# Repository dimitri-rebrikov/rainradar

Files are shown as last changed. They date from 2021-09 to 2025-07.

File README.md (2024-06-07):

# rainradar

Rain Radar (German: Regenradar)  displays the rain forecast on a 32x8 led matrix.
It shows the intensity of the rain for the next 2 hours with 5 minutes resolution 
and the intensity of the rain for the 6 hours (following the 2 hours) with 1 hour resolution.

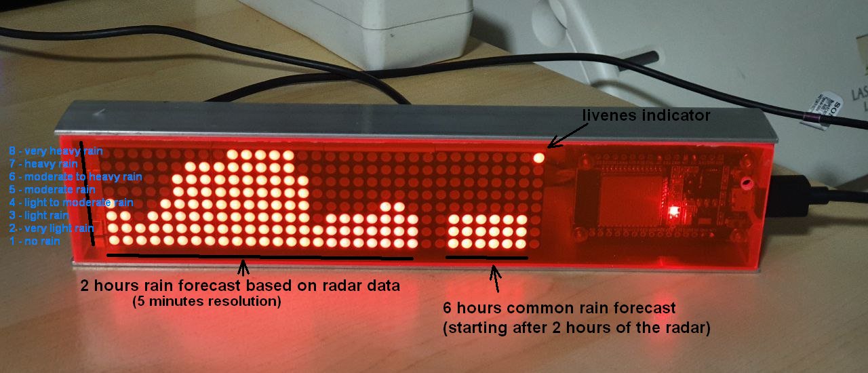
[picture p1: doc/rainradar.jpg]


# common
The Rain Radar consist of:

Frontend Device:
- an ESP32 micro controller
- a chain of four MAX7219 8x8 LED matrices
- source code implemented in MycroPython accessing to the backend and visualising the rain forecast data on the matrix

Backend/Online Services:
- AWS Lambda collecting rain radar data (Radolan RV) from the DWD (German Federal Weather Service) for all Gemran postal indexes (PLZ's)
- AWA Lambda collecting rain forecast data (Mosmix) from the DWD for all German postal indexes
- AWD Lambda providing rain radar and rain forecast data on a HTTP GET request with a German postal index as query parameter

The project is inspired by the project from the German Make Magazine https://github.com/MakeMagazinDE/LED-Laufschrift

# user manual for the device

See [User Manual](doc/manual/MANUAL.md)

# assembly of the device

See [Assembly](doc/assembly/ASSEMBLY.md)
# setup of the device

- install Silicon Labs CP210x VCP driver from silabs.com so your PC can communicate with the ESP32 
- install Python 3.x as the software used below depends on it
- flash the MicroPython image on the ESP32 as described in https://docs.micropython.org/en/latest/esp32/tutorial/intro.html
  - `pip3 install esptool`
  - `esptool.py erase_flash`
  - `esptool.py  write_flash -z 0x1000  ~/Downloads/esp32/micropython/esp32-20210902-v1.17.bin` (assuming you downloaded the image into %HOMEPATH%/Downloads/esp32/micropython)
- install the tool to copy the files to ESP32
  - `pip3 install adafruit-ampy`
  - `ampy --port COM4 ls` (Change COM4 to the port number valid on your PC. Look into the device manager for this. If ampy hangs try to add the delay paramter to the command, i.e. `ampy --port COM4 -d 1 ls`)
- download the `max7219.py` module from  https://github.com/mcauser/micropython-max7219
- upload the max7219 module to the ESP32
  - `ampy --port COM4 mkdir lib`
  - `ampy --port COM4 put ~/Downloads/esp32/micropython/max7219.py lib/max7219.py` (assuming you downloaded the module into %HOMEPATH%/Downloads/esp32/micropython)
  - `ampy --port COM4 ls lib`
- download this project (i.e. https://github.com/dimitri-rebrikov/rainradar)
- upload the rainradar code (i.e. the python modules *.py) to the ESP32
  - `ampy --port COM4 put ~/Downloads/esp32/rainradar/rainradar/ .` (assuming you downloaded the project into %HOMEPATH%/Downloads/esp32/rainradar)
  - `ampy --port COM4 ls`
- restart ESP32 by disconnecting/connecting the power supply (i.e. USB)

# backend

See [Backend](aws-backend/BACKEND.md)

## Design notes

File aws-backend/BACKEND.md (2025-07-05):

# setup
Theoretically you don't need your own backend as the frontend device will use my instance of the backend by default.

But for the case you want to have and use your own instance, here is the short description:
(to do this you need to have basic knowledge about Amazon Web Services)

- create 3 AWS Lambdas using the zipped content of the rainradar_* directories. For the rainradar_rv_update lambda you will also need to create a python layer, see the chapter below.
- configure the S3 bucket with the name "rainradar" and configure the read/write access to it for all 3 lambdas
- test all 3 lambdas
- create Event Bridge with 1 hour rate for the rainradar_mosmix_update lambda
- create Event Bridge with 2-5 min rate for the rainradar_rv_update lambda
- create API Gateway for the rainradar_get lambda. For the API Gateway you may also want to create throttling to prevent unexpected costs if someone runs a request attack to your endpoint
- the current frontend source code contains the hardcoded URL of my API Gateway so you need to adjust it to use you own

## rainradaf_rv_update python layer
The rainradar_rv_update lambda uses functions depending on the h5py python library. 
This library not only not included into the standard python distribution available on the AWS but also has hardware dependent part. So you need to create a layer for this

Commands to create the layer zip on your local machine:
- install the same python version you will use for the lambdas in AWS
- `mkdir python`
- `pip install h5py --platform manylinux2014_x86_64 --only-binary=:all: -t python`
- `zip -r layer.zip python/` (if you don't have zip command, just use the zipper of your choice, but pay attention that the 'python' directory is preserved inside of the the zip)

Then you just need to create a new layer in your AWS environment and upload the 'layer.zip' as its content.

Later during the creation of the rainradar_rv_update lambda you shall configure it to use this layer.

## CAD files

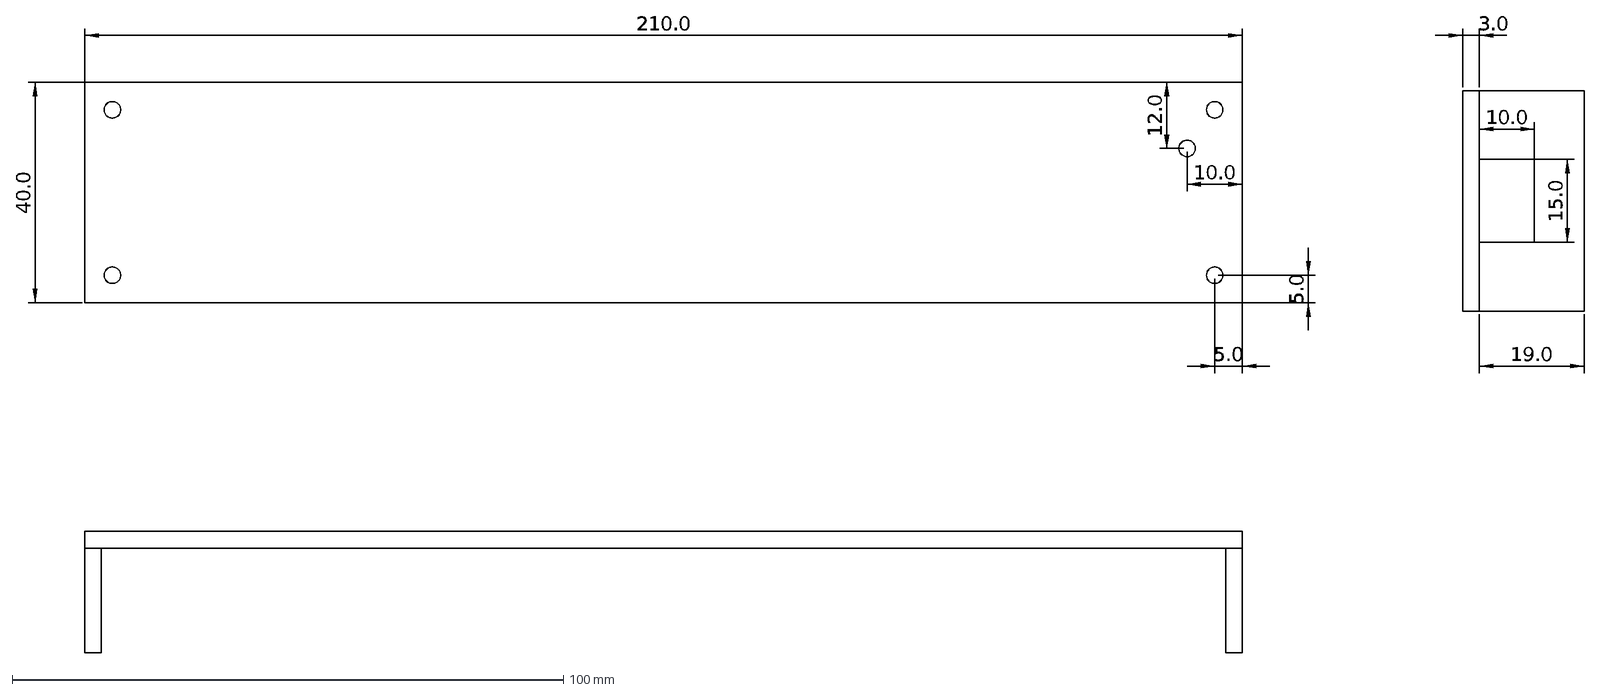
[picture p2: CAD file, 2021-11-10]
doc/assembly/lid.dxf
5.0
40.0
210.0
12.0
10.0
3.0
15.0
19.0

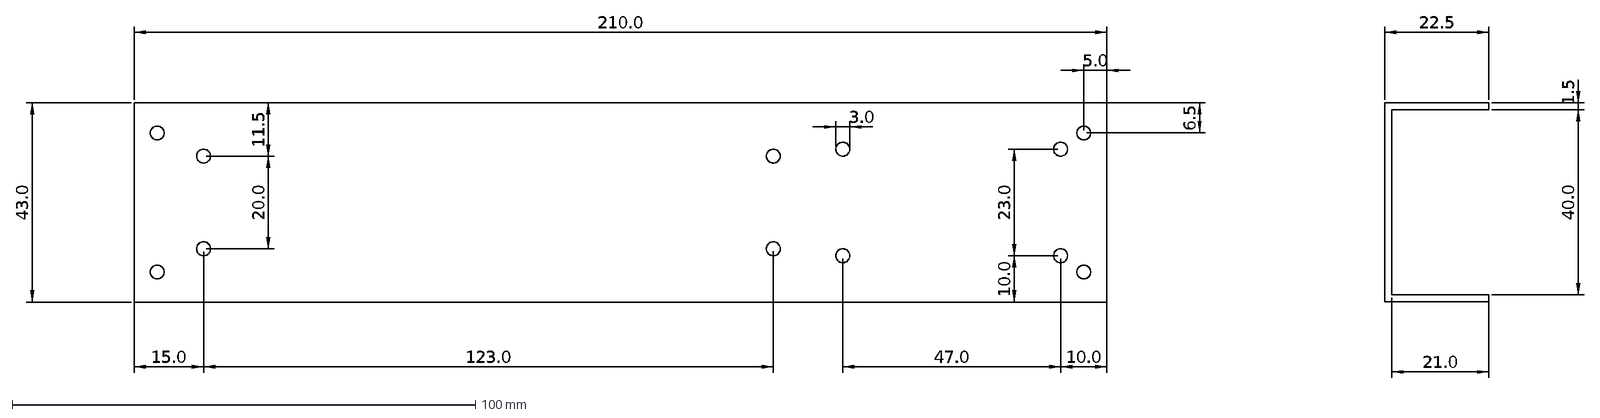
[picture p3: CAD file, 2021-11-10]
doc/assembly/casing.dxf
210.0
22.5
40.0
1.5
21.0
3.0
47.0
123.0
10.0
5.0
6.5
15.0
43.0
23.0
20.0
11.5

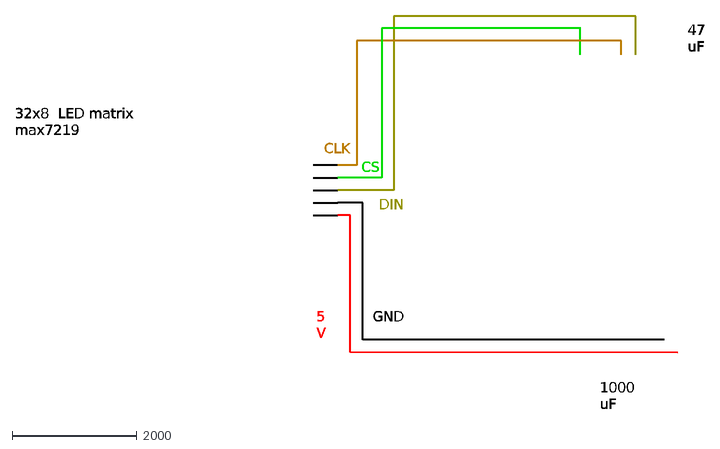
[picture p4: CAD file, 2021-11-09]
doc/assembly/schematic.dxf
32x8 LED matrix max7219
47 uF
1000 uF
GND
5 V
CLK
CS
DIN

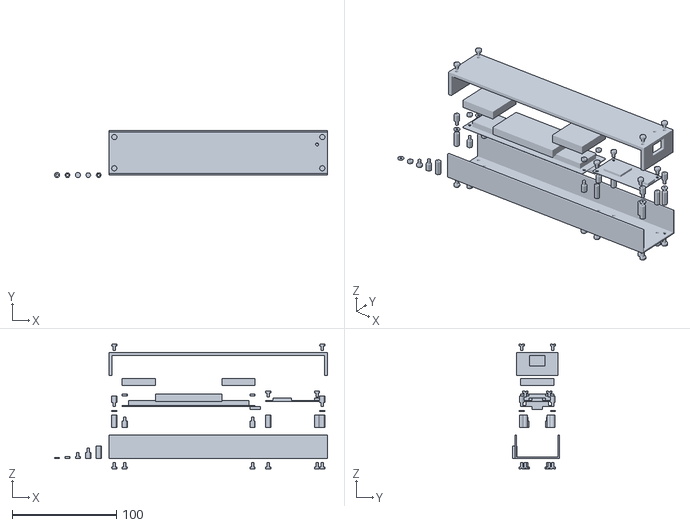
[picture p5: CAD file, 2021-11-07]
doc/assembly/exploded_view.stl
262.5 x 45.5 x 120.0

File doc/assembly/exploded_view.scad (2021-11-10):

$fn=20;

/*
positions of the drilling holes
*/
dhLid1=[5,6.5,0];
dhLid2=[5,36.5,0];
dhLid3=[205,6.5,0];
dhLid4=[205,36.5,0];
dhLed1=[15,11.5,0];
dhLed2=[15,31.5,0];
dhLed3=[138,11.5,0];
dhLed4=[138,31.5,0];
dhEsp1=[153,10,0];
dhEsp2=[153,33,0];
dhEsp3=[200,10,0];
dhEsp4=[200,33,0];

module parts() {
    // just to show all parts necessary
    translate([-10,0,0]) standoff12FF();
    translate([-20,0,0]) standoff06MF();
    translate([-30,0,0]) screw();
    translate([-40,0,0]) screwNut();
    translate([-50,0,0]) washer();
}

module explode_view() {
    // explode view of elements
    casingWithHoles();
    translate([0,0,-10]) bottomScrews();
    translate([0,0,30]) {
        ledStandoffs();
        espStandoffs();
        lidStandoffs1();
    }
    translate([0,0,45]) lidWashers();
    translate([0,0,60]) lidStandoffs2();
    translate([0,0,50]) ledBase();
    translate([0,0,55]) esp();
    translate([0,0,65]) espScrews();
    translate([0,0,60]) ledScrewNuts();
    translate([0,0,70]) ledUnmounted();
    translate([0,0,80]) lid();
    translate([0,0,110]) lidScrews();
}

parts();
explode_view();
// or
// projection for creating a dxf file for casing drillings
//projection(cut=true) translate([0,0, -1])
//    casingWithHoles();
// or
// projection for creating a dxf file for casing side view
//projection(cut=true) translate([0,0, 1]) rotate([0,90,0])
//    casingWithHoles();
// or
// projection for creating a dxf file for lid
//projection(cut=true) translate([0,0, -20])
//    lid();
// or
// projection for creating a dxf file for lid USB side
//projection(cut=true) translate([0,0, 209]) rotate([0,90,0])
//    lid();
// or
// projection for creating a dxf file for lid cross section
//projection(cut=true) translate([0,0,2]) rotate([-90,0,0])
//    lid();


module standoff12FF() {
    /*
    standoff m2.5 x 12 mm
    */
    difference(){
        cylinder(d=5,h=12,$fn=6);
        cylinder(d=2.5,h=12,$fn=50);
    }
}

module standoff06MF() {
    /*
    standoff m2.5 x 6 mm + 4 mm
    */
    difference(){
        cylinder(d=5,h=6,$fn=6);
        cylinder(d=2.5,h=5,$fn=50);
    }
    translate([0,0,4]) cylinder(d=2.5,h=6,$fn=50);
}

module screw() {
    /*
    screw m2.5
    */
    difference() {
        cylinder(d=5,h=2,$fn=50);
        translate([-2.5,-0.5,0]) cube([5, 1, 1]);
    }
    translate([0,0,2]) cylinder(d=2.5,h=4,$fn=50);
}

module screwNut() {
    /*
    screw nut m2.5
    */
    difference(){
        cylinder(d=5,h=2,$fn=6);
        cylinder(d=2.5,h=2,$fn=50);
    }
}

module washer() {
    /*
    washer m2.5 x 1 mm
    */
    difference(){
        cylinder(d=5,h=1,$fn=50);
        cylinder(d=2.5,h=1,$fn=50);
    }
}

module drillingHole() {
    cylinder(d=3,h=3,$fn=50);
}

module casing() {
    cube([210,43,1.5]);
    cube([210,1.5,22.5]);
    translate([0,41.5,0]) cube([210,1.5,22.5]);
}

module repeatForPositions(positions) {
    for( position = positions ) {
        translate(position) children();
    }
}

module repeatForLidDrillingHoles() {
    repeatForPositions([dhLid1,dhLid2,dhLid3,dhLid4]) 
        children();
}

module repeatForLedDrillingHoles() {
    repeatForPositions([dhLed1,dhLed2,dhLed3,dhLed4]) 
        children();
}

module repeatForEspDrillingHoles() {
    repeatForPositions([dhEsp1,dhEsp2,dhEsp3,dhEsp4]) 
        children();
}

module casingWithHoles() {
    difference() {
        casing();
        repeatForLidDrillingHoles() 
            drillingHole();
        repeatForLedDrillingHoles() 
            drillingHole();
        repeatForEspDrillingHoles() 
            drillingHole();
    }
}

module bottomScrews() {
    repeatForLidDrillingHoles() 
        screw();
    repeatForLedDrillingHoles() 
        screw();
    repeatForEspDrillingHoles() 
        screw();
}

module lidWashers() {
    repeatForLidDrillingHoles() 
        washer();
}

module ledStandoffs() {
    repeatForLedDrillingHoles()
        standoff06MF();
}

module espStandoffs() {
    repeatForEspDrillingHoles()
        standoff12FF();
}

module lidStandoffs1() {
    repeatForLidDrillingHoles()
        standoff12FF();
}

module lidStandoffs2() {
    repeatForLidDrillingHoles()
        rotate([180,0,0])
            standoff06MF();
}

module esp() {
    difference() {
        translate(dhEsp1) {
            translate([-2.5, -2.5, 0]) {
                cube([52,28,1]);
                translate([7,6,1]) cube([18,16,2]);
                translate([47,9,0]) cube([5,10,3]);
            }
        }
        repeatForEspDrillingHoles() 
            drillingHole();
    }
    
}

module espScrews() {
    repeatForEspDrillingHoles()
        rotate([180,0,0])
            screw();
}   

module ledBase() {
     difference() {
        translate(dhLed1) {
            translate([-2.5, -6, 0]) {
                cube([128,32,1]);
                translate([123,11,-3]) cube([10,10,3]);
                translate([6,5,1]) cube([116,22,5]);
                translate([32,0,5]) cube([64,32,7]);
            }
        }
        repeatForLedDrillingHoles() 
            drillingHole();
    }
}

module ledScrewNuts() {
    repeatForLedDrillingHoles()
        screwNut();
}   

module ledUnmounted() {
    translate(dhLed1) {
        translate([-2.5, -6, 0]) {
            cube([32,32,7]);
            translate([32*3,0,0]) cube([32,32,7]);
        }
    }
}

module lidTop() {
   difference() {
        cube([210,40,3]);
        translate([0,-1.5,0]) repeatForLidDrillingHoles() 
            drillingHole();
        translate([200,28,0])
            drillingHole();
   }
}

module lidSide() {
    cube([3,40,19]);
}

module lidSideUsb() {
    difference() {
        lidSide();
        translate([0,12.5,9]) cube([3,15,10]);
    }
}

module lid() {
    translate([0,1.5,0]) {
        translate([0,0,19]) lidTop();
        lidSide();
        translate([207,0,0]) lidSideUsb();
    }
}

module lidScrews() {
    repeatForLidDrillingHoles()
        rotate([180,0,0])
            screw();
}     

    

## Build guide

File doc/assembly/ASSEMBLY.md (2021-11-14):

# Assembly of the Rain Radar

The assembly idea is based on the project from the German Make Magazine https://github.com/MakeMagazinDE/LED-Laufschrift

## Electronic

### Bill of Material

| No | Part Designation | Remark |
|----|---|---|
| 1 | ESP32 Dev Kit Board | The variant with 4 mounting holes and without soldered headers |
| 2 | 34 x 8 LED Matrix MAX7219 | Actually it is assembly of 4x LED matrix modules sold soldered together |
| 3 | Tantal Elco 47 uF | Optional. Shall make the ESP32 working more reliable |
| 4 | Elco 1000 uF | Optional. Shall make the device working more reliable |
| 5 | 5 x single Socket to Socket Jumper Wire | Probably you will get some with the LED Matrix but some of different colors are preferable to avoid soldering errors |

### Schematic

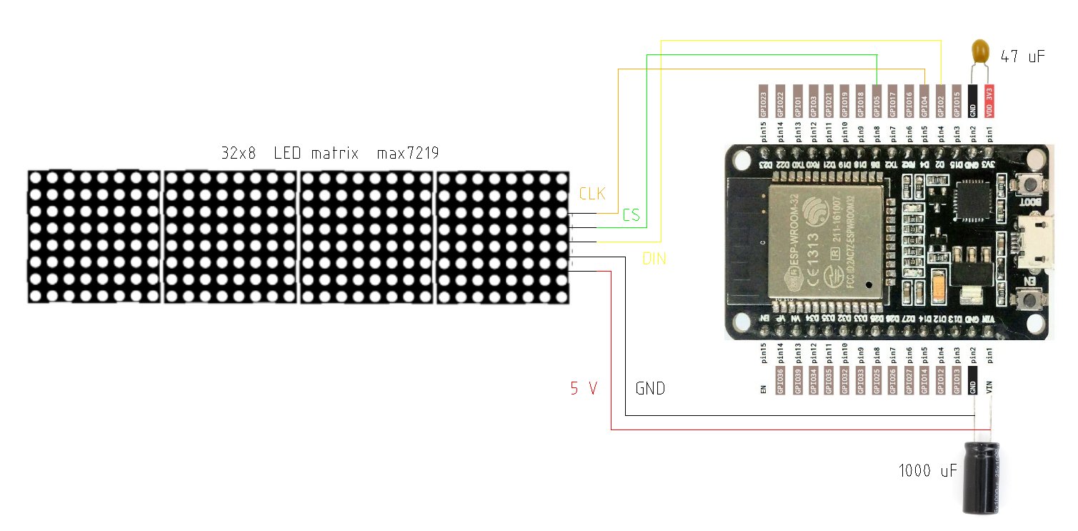
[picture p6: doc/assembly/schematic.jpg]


### Soldering

1. Solder the 1000 uF Elco to the contacts VIN and GND of the ESP32
2. Solder the 476 uF Elco to the contacts 3V3 and GND of the ESP32
3. Remove the sockets from on side of the jumper wires so you can solder this side to the ESP32 and connect the remaining socket on the another side to the plug on the LED matrix
4. Solder the jumper wires to D2, D4 and D5 contacts of the ESP32
5. Solder 2 jumper wires directly to the legs of the 1000 uF Elco

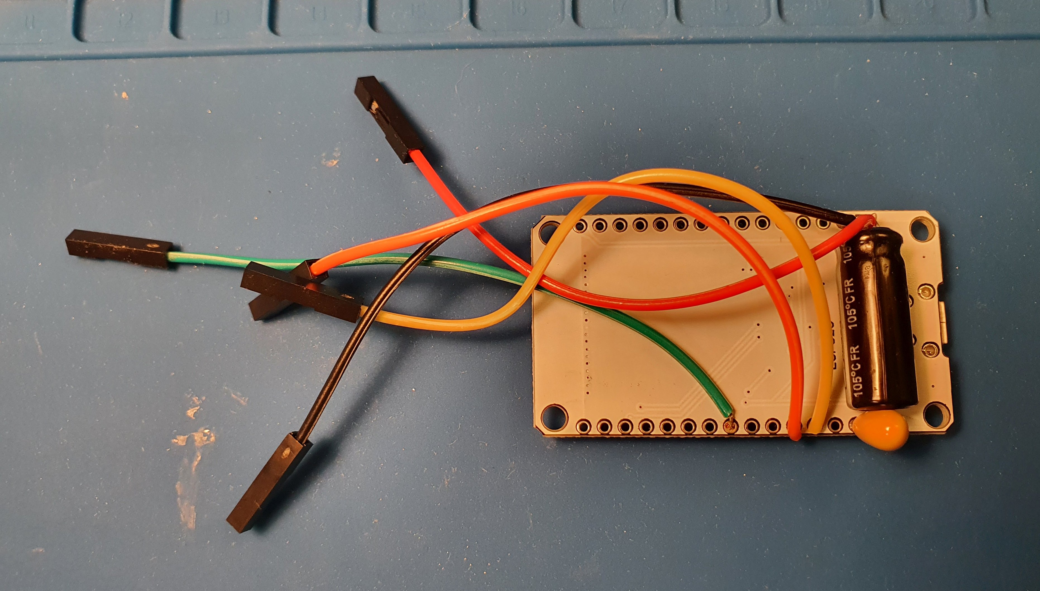
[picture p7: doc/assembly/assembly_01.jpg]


### Connection

Connect the sockets of the soldered wires to the LED matrix according to the following table:

| ESP32 | LED Matrix |
|---|---|
| VIN |	VCC |
| GND |	GND |
| D2 | DIN |
| D4 | CLK |
| D5 | CS |

Remark: the table corresponds to the documentation from https://github.com/mcauser/micropython-max7219

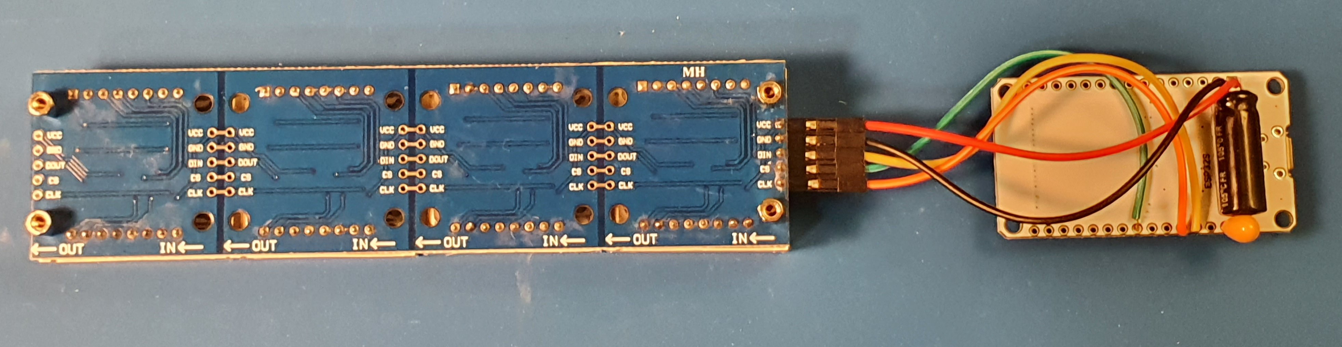
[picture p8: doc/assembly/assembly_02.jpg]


## Encasing

### Bill of Material

| No | Part Designation | Remark |
|----|---|---|
| 1 | Aluminum U profile 43.5 x 23.5 , 1.5mm thick | my was 1000mm long |
| 2 | Transparent acrylic glass plate 3mm thick | I used PLEXIGLAS® Cherry GS 3C01,  120 x 250 mm  |
| 3 | 8x 12mm m2.5 brass standoffs female-female | |
| 4 | 8x 6mm m2.5 brass standoffs female-male | |
| 5 | 20x m2.5 screws | |
| 6 | 4x m2.5 screw nuts | |
| 7 | 4x m2.5 washers 1mm thick | |

Remark: I bought all standoffs, screws, nuts, washer as a set on eBay.

### Aluminum Back

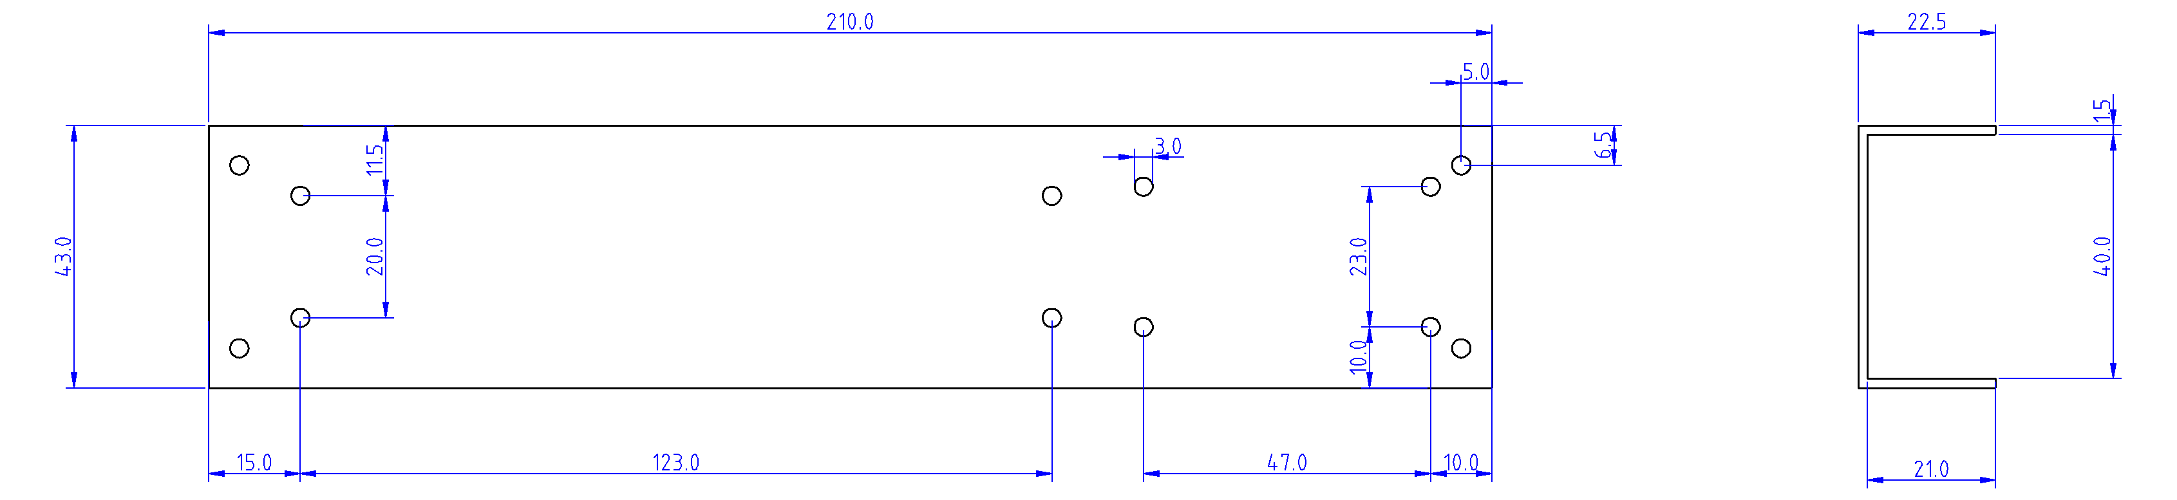
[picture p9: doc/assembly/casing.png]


1. Cut the U profile to the length of 210 mm and sand the sharp edges
2. Drill the 3mm holes according to the plan. I used a drilling machine put into a drill stand for this.

### Acrylic lid

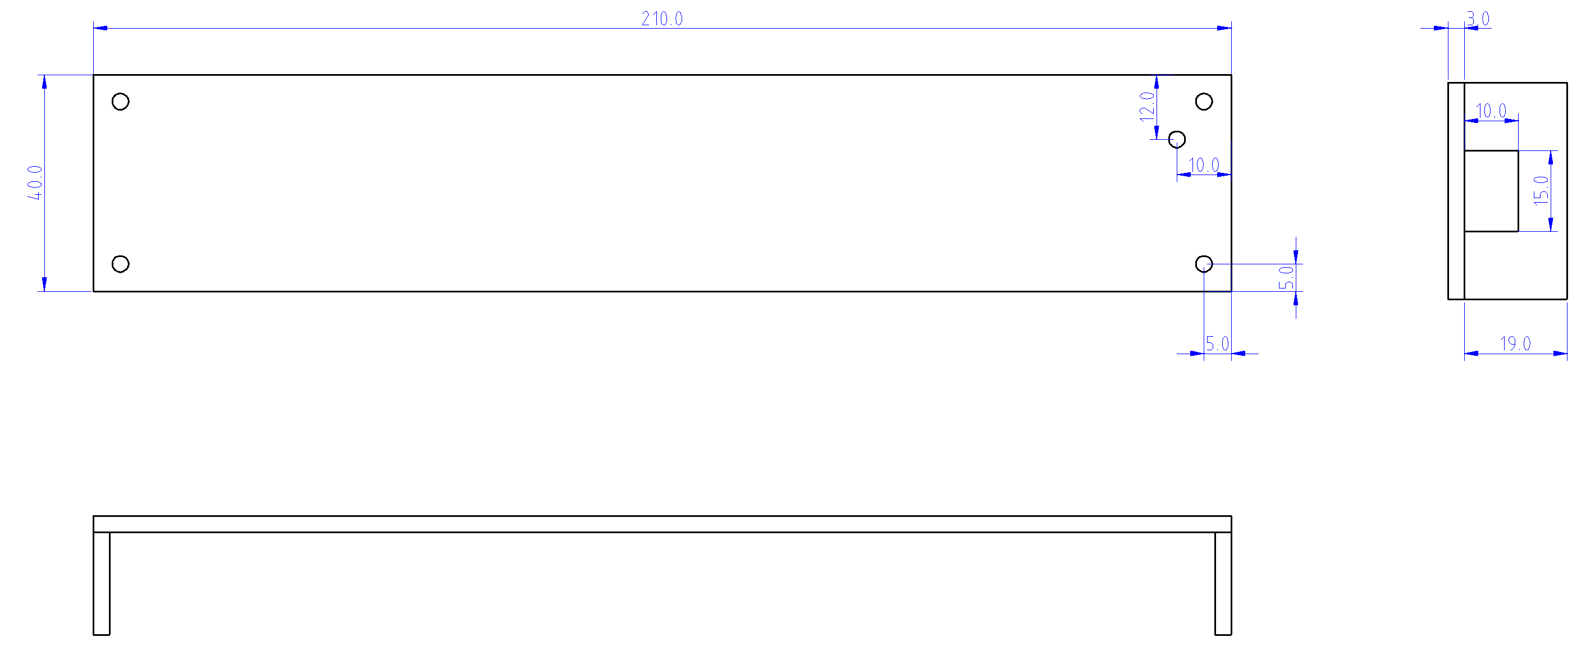
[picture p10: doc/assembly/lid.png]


1. Cut the 40mm broad strip from the acrylic plate. I used the metal level ruler and the carpet knife for this.
2. Cut a piece of 210mm and 2 pieces of 19mm from the strip. I used the hacksaw for this.
3. Cut the USB socket opening in one of the short pieces. I used the fretsaw for this.
4. Drill the 5x 3mm holes according to the plan.
5. Stick the 3 pieces together according to the plan. I used the Super Glue.

### Put everything together 

For the idea of assembling everything together see the pictures below.

Just few remarks:
- The standoffs for the lid are build from the combination of:
  - 6mm standoff nut-screw
  - 1mm washer
  - 12mm standoff nut-nut
 
  to implement the length of the 19mm 
- The standoffs for the LED module are 6mm long. As the LED module is 13mm height this makes it fits perfectly under the lid. If you use a nut-screw standoff you will probably don't need to remove the 2 outside LED matrixes as you can just slide the nuts under them and screw them together with the standoff as seen on the picture below. On the same picture there are washers under the LED standoffs. This was made because for this rainradar exemplar I run out of the 6mm standoffs and used the 5mm version with the addition of the 1mm washer instead.

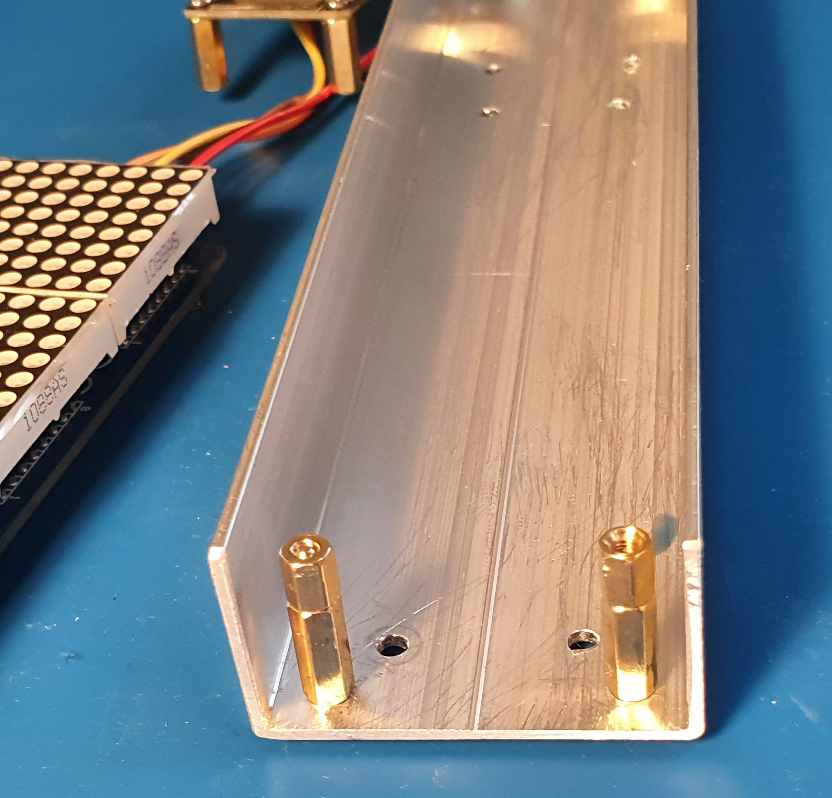
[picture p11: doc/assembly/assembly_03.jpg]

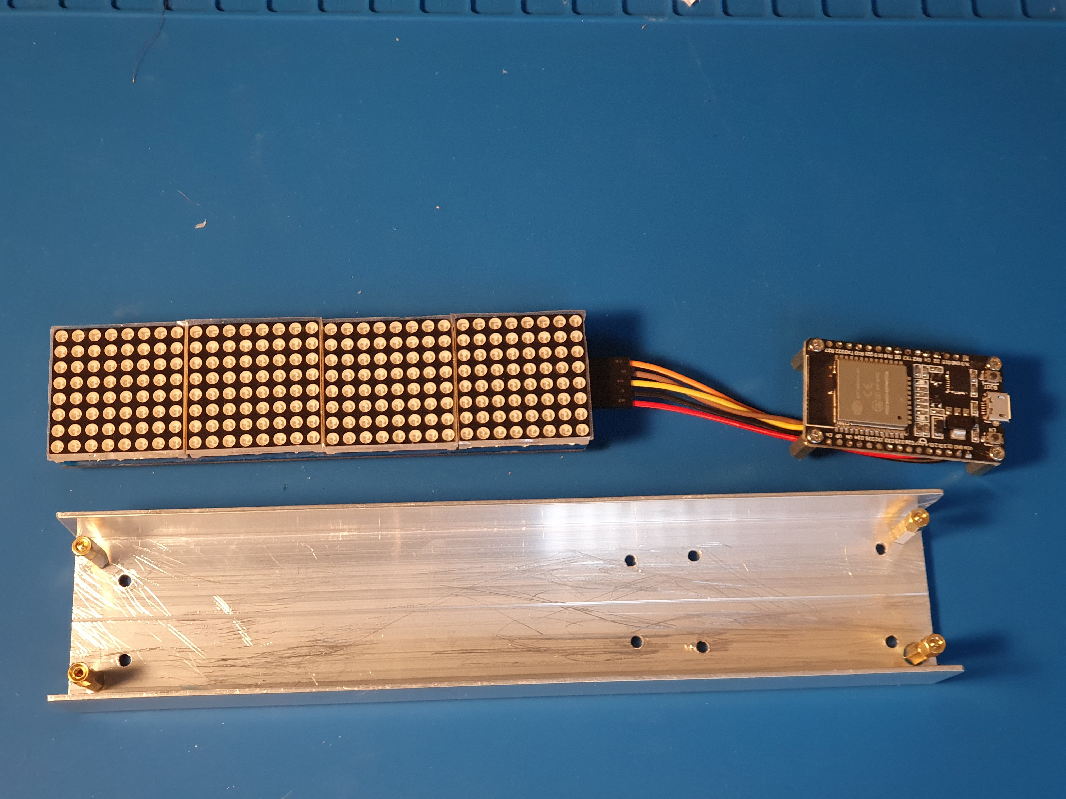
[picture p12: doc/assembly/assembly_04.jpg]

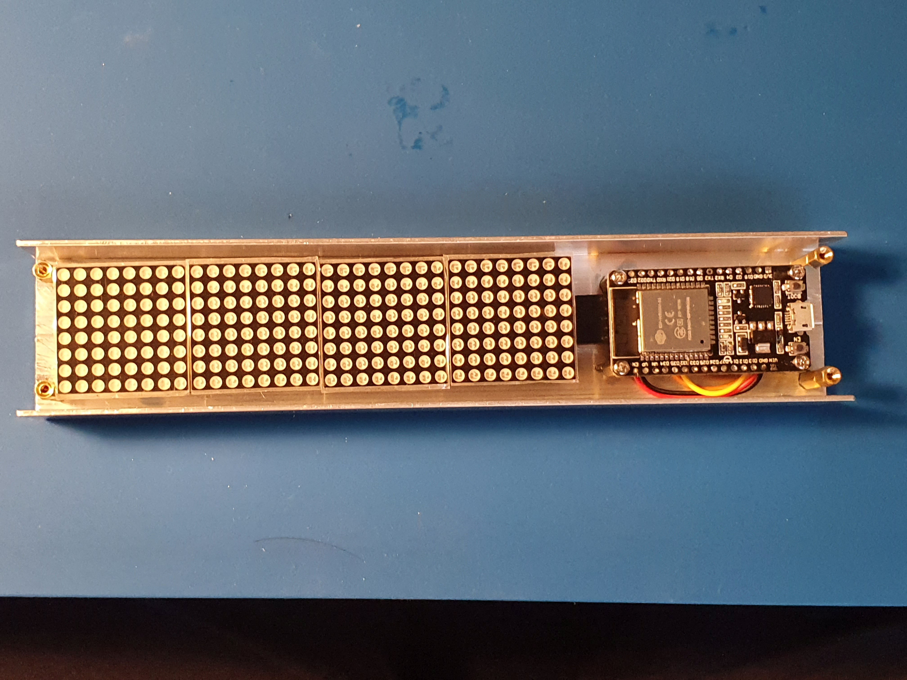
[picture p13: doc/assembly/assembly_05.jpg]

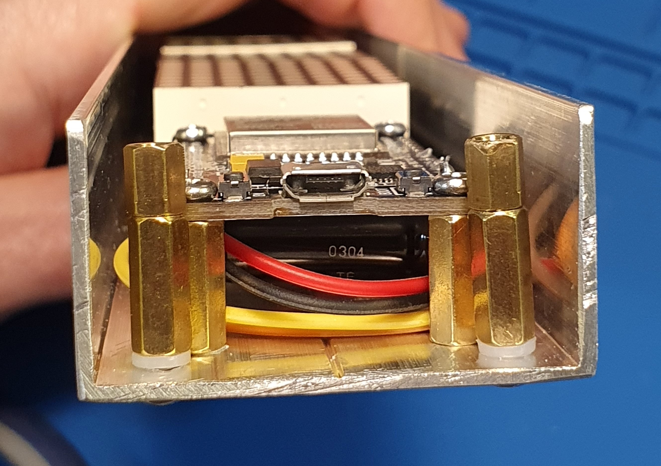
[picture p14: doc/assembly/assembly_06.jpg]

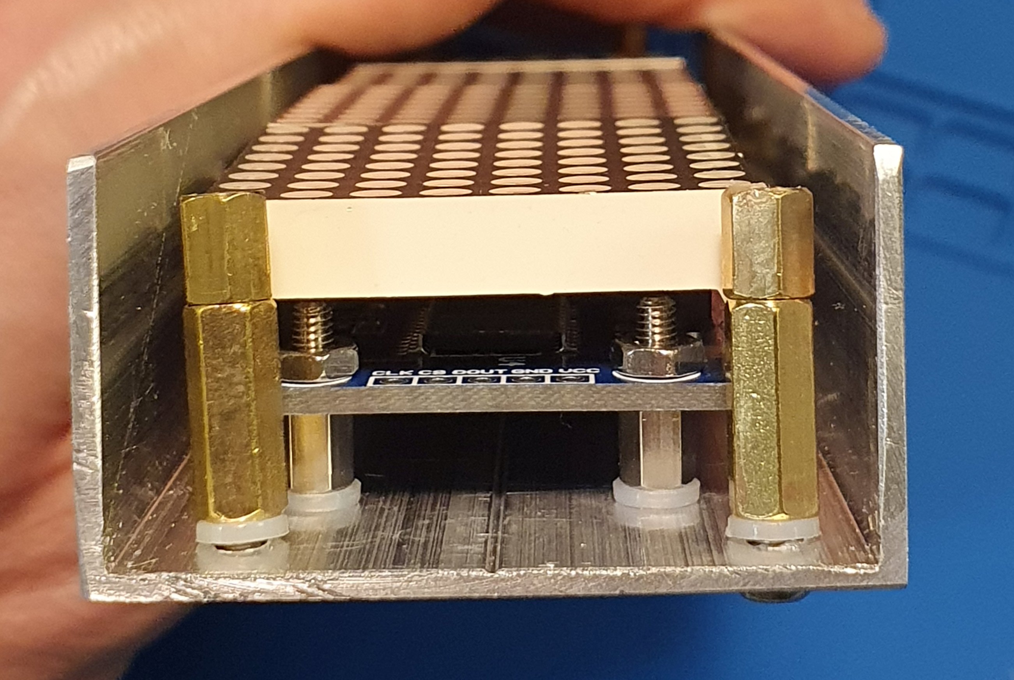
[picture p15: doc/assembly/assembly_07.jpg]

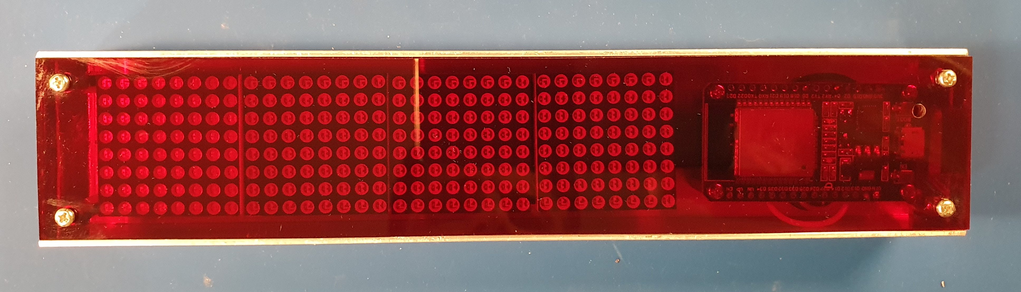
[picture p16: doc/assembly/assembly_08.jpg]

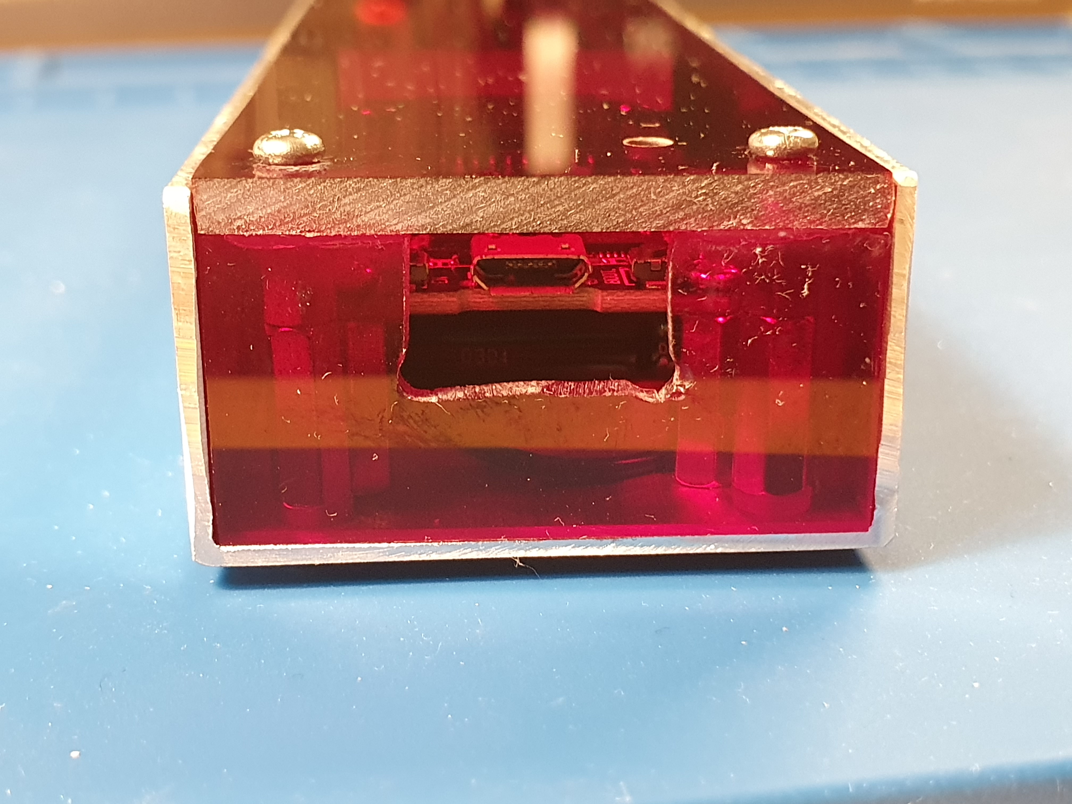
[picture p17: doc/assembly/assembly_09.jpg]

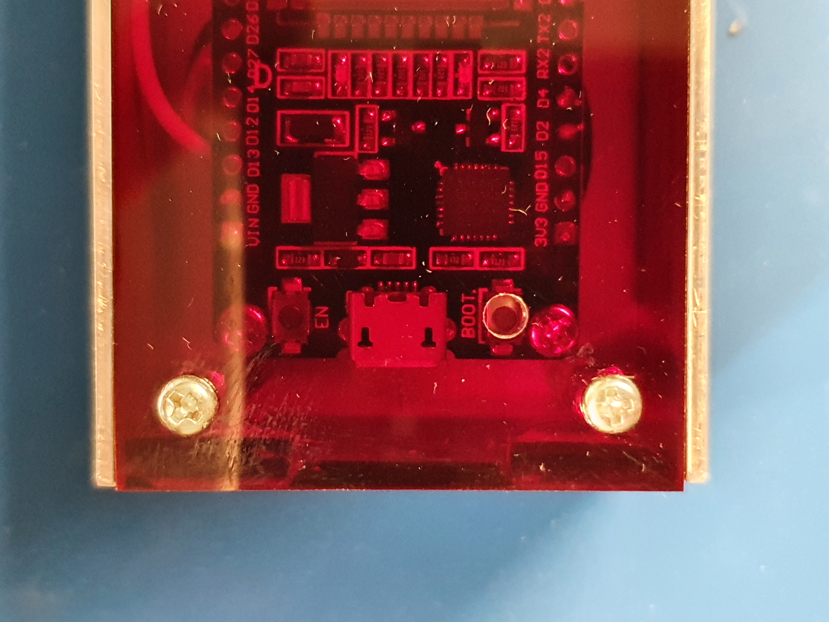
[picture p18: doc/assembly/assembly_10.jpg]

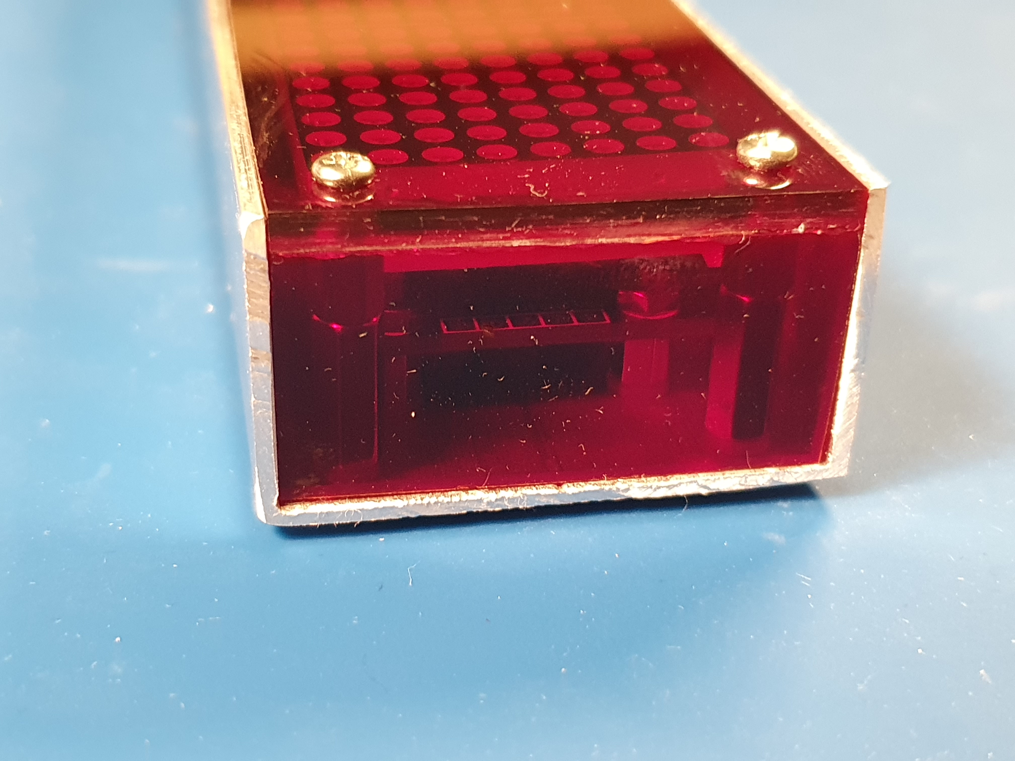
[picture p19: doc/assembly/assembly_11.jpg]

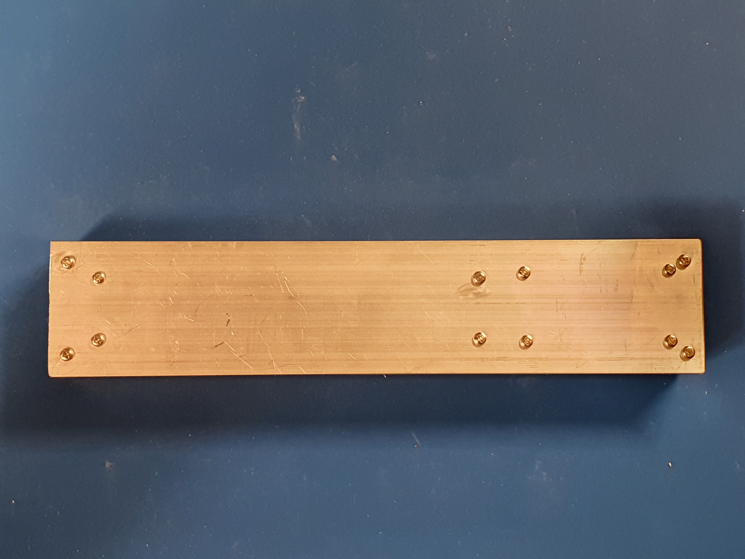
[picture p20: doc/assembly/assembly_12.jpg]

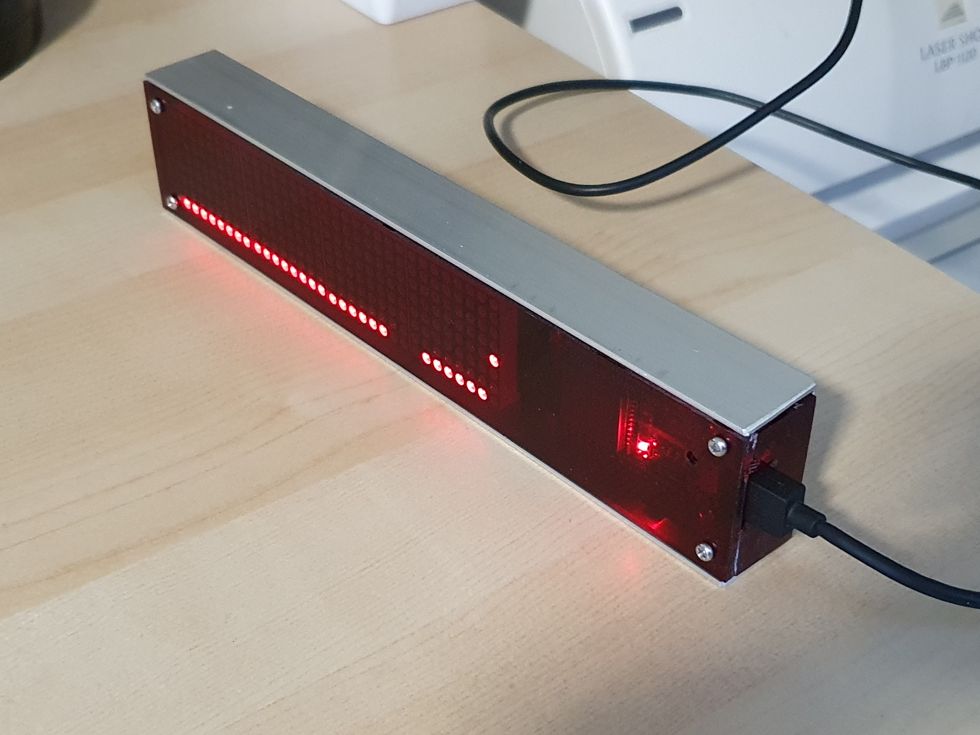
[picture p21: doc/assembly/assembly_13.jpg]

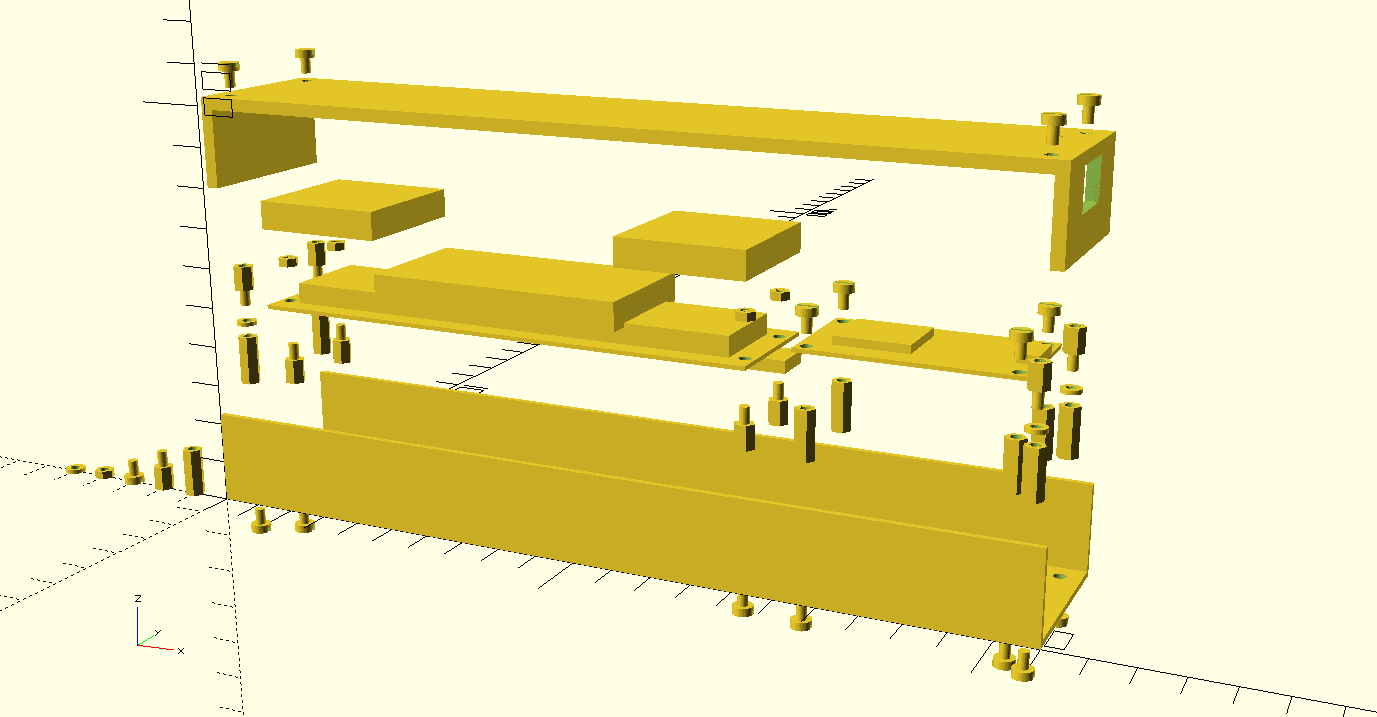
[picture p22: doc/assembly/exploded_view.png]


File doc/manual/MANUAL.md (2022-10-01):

# Manual for the Rainradar

## Controls and Connectors

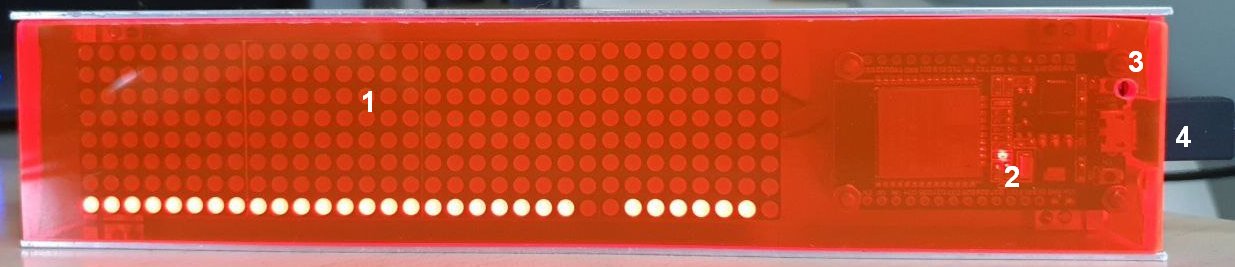
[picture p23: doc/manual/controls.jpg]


1. Display
2. Power LED
3. Configuration Mode Button
4. Micro USB Socket 

## Operational Mode

**For the initial configuration see:** [Configuration Mode](#configuration-mode)

In this mode the Rainradar displays the short term rain forecast in the left part of the display and middle term rain forecast in the right part.

The short term forecast shows the rain levels for the coming 2 hours with the resolution of 5 min.

The middle term forecast show the rain levels for the 6 hours after the 2 hours of the short term forecast. The resolution is 1 hour.

Additionally there is a blinking LED on the right edge of the display representing the liveness of the device. The distance of this LED to the upper corner of the display  represent the amount of time (in minutes) to the next refresh of the rain levels.

**Remark**
During the start (i.e. after powering of the Rainradar over the Micro USB connector) the Rainradar shows for some seconds the Postal Index it configured to provide the forecast for.

### Rain Levels

The rain levels are presented as a bar diagram. The height of the particular bar (i.e. the number of the shining LED's in the bar) visualizes the intensity of the rain in the corresponding time period.

The following table references the number of the LED's in the bar to the corresponding rain level:

| Number of the LED's | Rain Level in Text | Rain Level in mm/h |
|---|---|---|
| 1 | No Rain | < 0.1 |
| 2 | Very Light Rain | 0.1 to 1.2 |
| 3 | Light Rain | 1.2 to 2.5 |
| 4 | Light to Moderate Rain | 2.5 to 5.5 |
| 5 | Moderate Rain | 5.5 to 10 |
| 6 | Moderate to Heavy Rain | 10 to 25 |
| 7 | Heavy Rain | 25 to 50 |
| 8 | Very Heavy Rain | from 50 |

### Example

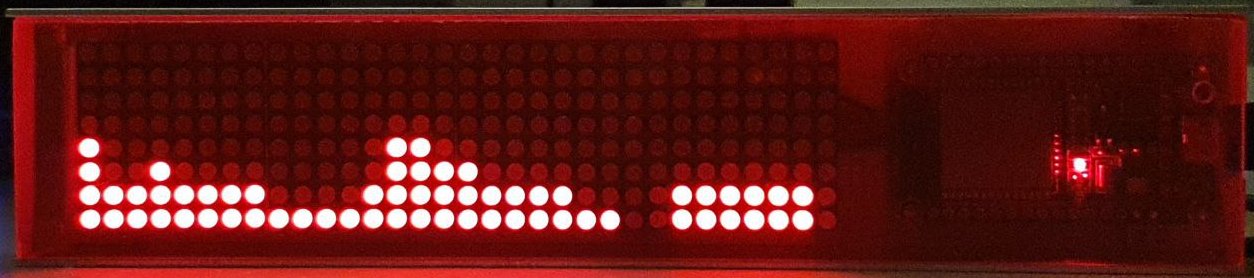
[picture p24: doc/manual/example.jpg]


This example represents the following situation:

**Short Therm Part on the Left**

- in the next 5 minutes there will be the light to moderate rain (the first bar with 4 LED's)
- after that there will be very light or light rain (the next 7 LED bars with 2 or 3 LED's in each) for 35 min (7 x 5 = 35)
- after that there will be no rain for 20 minutes (the 4 LED bars with only one LED in each)
- after that (so ca. after 1 hour from now) there will be light to moderate rain for ca. half of an hour which then will decline.

**Middle Therm Part on the Right**

For the time period starting with 3 to 8 hours from now there will be probably very light rain.

### Errors

In case of application errors during the Operational Mode they are shown for some seconds on the display. After that the application restarts.

The following table show know errors:

| Error on Display | Meaning | Possible Issue | Possible solution |
|---|---|---|---|
| **ERR WIFI** | The Rainradar could not connect to the WiFi network | No connection to the WiFi router | Fix the WiFi connection to the router, see [Configuration Mode](#configuration-mode) |
| **ERR NTP** | The Rainradar could not connect to the NTP server to synchronize its clock |  No connection to the internet | Fix connection to the internet in the WiFi router |
| **ERR GET RADAR** or **ERR GET RAIN**| The Rainradar could not get the weather information from the server. | No connection to the internet | see above |
|  |  | The server providing the radar information is broken/down | The Rainradar uses the [morgenwirdes](https://morgenwirdes.de/api/) server to get the information. Try to visit the site to get more information |
| **ERR JSON RADAR** or **ERR JSON RAIN**| The Rainradar could not parse the information provided by the server | The server providing the weather information is broken | see above |

In case you suspect the issues in the application itself you can raise an [issue ticket](https://github.com/dimitri-rebrikov/rainradar/issues)

## Configuration Mode

The configuration mode allows to change the parameters necessary for the [Operational Mode](#operational-mode):

- the credentials (SSID and password) of the WiFi network the Rainradar shall connect for
- the German postal index code (PLZ) the Rainradar shall provide the rain forecast for

During the initial start (i.e. if there is no configuration) the Rainradar will automatically switch into the Configuration Mode.

To switch into configuration mode any time later you shall press the configuration button through the hole in the lid. Please use a thin non-metal stick for this, for example a toothpick. The button will make a haptic noticeable click. The switch into the configuration mode might take some seconds if the device is currently displaying the error message or make some other processing which cannot be interrupted.

After switching into the Configuration Mode the Rainradar will show "CONF" on the display.

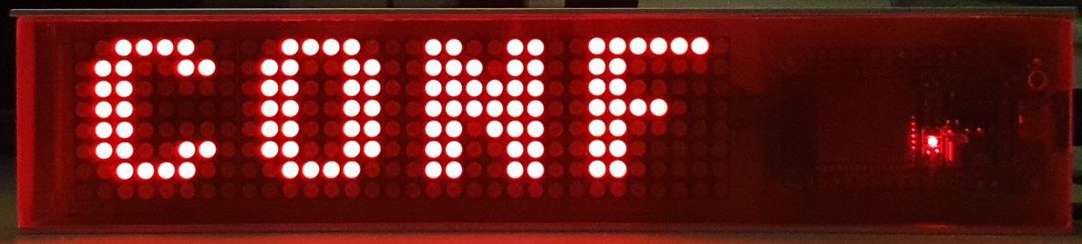
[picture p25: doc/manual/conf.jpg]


To configure the Rainradar you shall directly connect to it over direct WiFi connection.

### Connect to Rainradar over direct WiFi connection

In the Configuration Mode the Rainradar starts its own WiFi Access Point.
Open the WiFi configuration dialog in your device (PC, mobile phone etc) and search for  WiFi network with the name "rainradar".

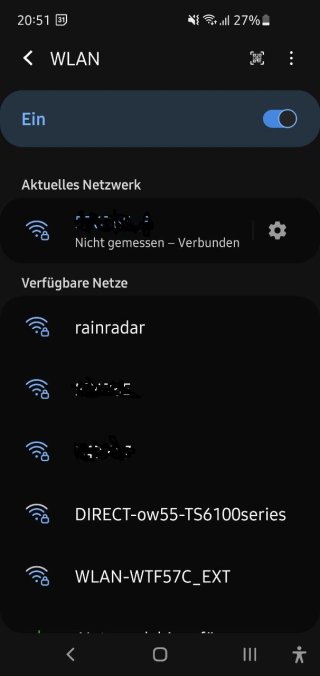
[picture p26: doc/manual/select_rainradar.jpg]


Connect to this Access Point using the following password: *rainradar2021*

After successful connection you might get warning that there is no connection to the internet over this network. This is ok and by intention, as now you connected directly and exclusively only to the Rainradar.

Now open the address [http://192.168.4.1](http://192.168.4.1) in the Web Browser and the Rainradar configuration page shall be displayed.

### Configuration Page 

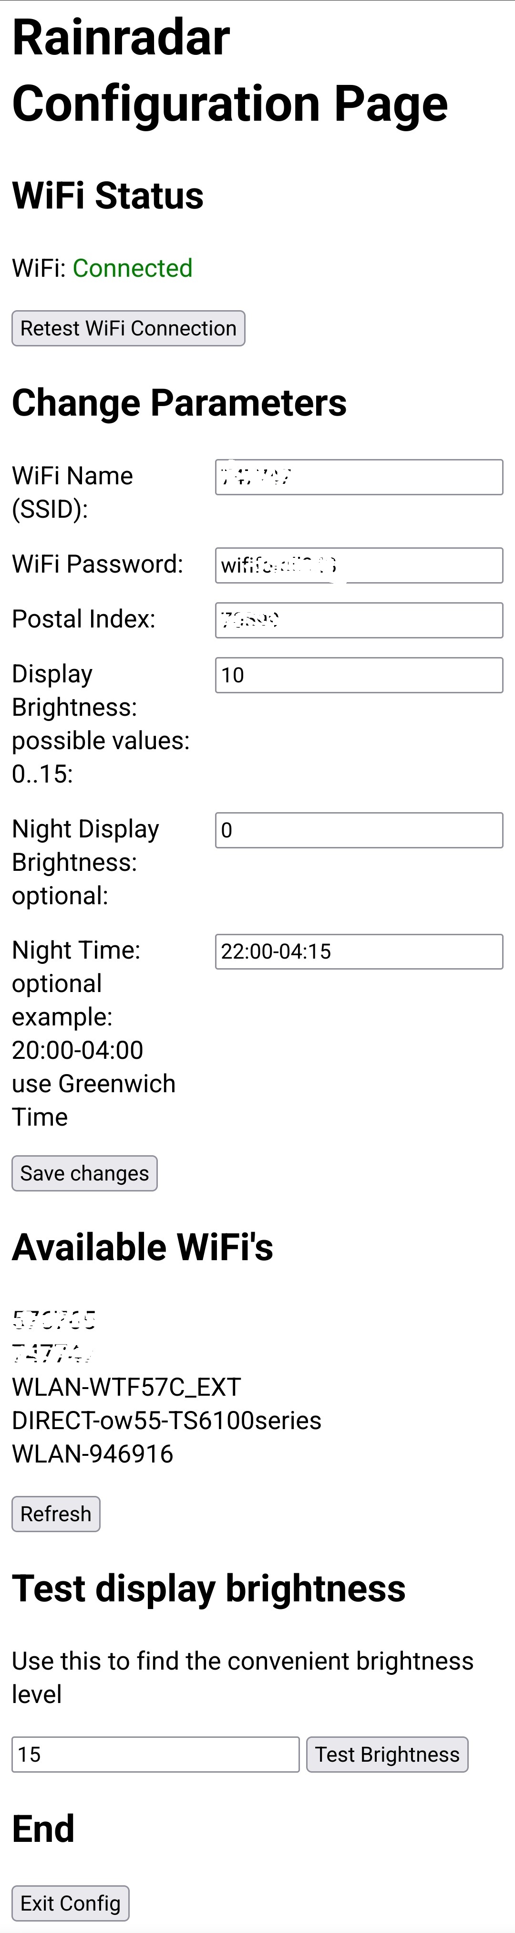
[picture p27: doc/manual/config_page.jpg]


#### WIFI Status

The chapter displays the status of the connection from Rainradar to your WiFi network. The button `Reset WiFi Status` will retest the connection to the WiFi and provide the new status.

#### Change Parameters

`WiFi Name (SSID)` the name of the WiFi network (also called SSID) the Rainradar shall connect to. This shall be probably your home WiFi. The chapter `Available WiFi's` below lists all WiFi networks discovered by the Rainradar.

`WiFi Password` the password for the WiFe network above.

`Postal index` the German postal index (so called PLZ) of your location. Rainradar will use this PLZ to get the rain radar and rain forecast data from the server.

`Display Brightness` lets you setup the brightnes of the LEDs. To test the brightness without saving and find the value comfortable for you use the `Test Display Brightness` chapter below.

`Night Display Brightness` this optional parameter lets you define the LED brightness for the night time. For this case the night time shall be also defined.

`Nitght Time` hier you can define the time period for the night brightness settings. Format: HH:MM-HH:MM 

After your configured all desired parameters you shall hit the "Save changes" button. 

The Rainradar will try to connect to the WiFi and provide the result in the "WiFi Status" chapter. If the status is "Not connected" the issues might be the following:
| Issue | Solution |
|---|---|
| Wrong WiFi name or password | Correct the data and hit "Save changes" again |
| The WiFi network does not allow connection of the "unknown" devices | Configure your WiFi router accordingly. i.e. Either remove the protection or add the Rainradar to the list of the know devices. After that hit the "Retest WiFi Connection" button for a new try |
| The WiFi network signal is to weak | Search a location near to the WiFi router and hit the "Retest WiFi Connection" button for a new try |

**Attention:** there is no check for the right postal index so ensure you provided correct value. Otherwise the rain forecast will be wrong.

After successful configuration you can exit the config mode by hitting of the `Exit Config` button. The Rainradar will stop its Access Point, so the connection to the Rainradar will be lost and your device will probably automatically connect to your home network again.

The Rainradar will switch back into the [Operational Mode](#operational-mode)

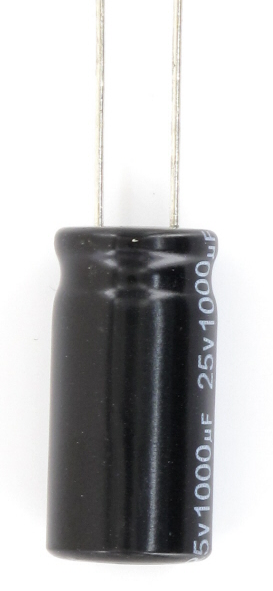
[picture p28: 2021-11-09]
doc/assembly/elko.png

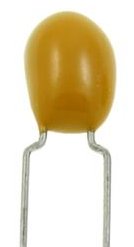
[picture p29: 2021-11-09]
doc/assembly/tantal.jpg

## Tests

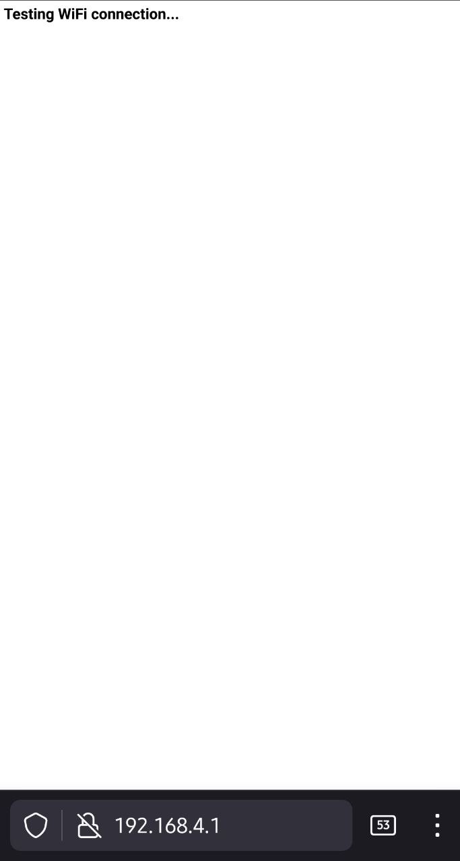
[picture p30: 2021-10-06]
doc/manual/testing_connection.jpg

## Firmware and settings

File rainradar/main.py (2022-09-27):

import time
from display import Display
from radar import Radar
import wifi
from config import Config
from exception import RainradarException
import ntptime
import math
from config_changer import ConfigChanger
import machine
import urandom
import gc
import sys
from timeframe import TimeFrame

syncTimePeriod = 60*60 # 1 hour

configMode = 0

def log(text):
    print(getCurrentTime() + ": " + text)

def bootButtonCallback(pin):
  global configMode
  log("boot button pressed")
  configMode = 1
  
bootButton = machine.Pin(0, machine.Pin.IN, machine.Pin.PULL_UP)
bootButton.irq(trigger=machine.Pin.IRQ_FALLING, handler=bootButtonCallback)

def syncTime():
    global syncTimePeriod, lastSyncTime
    if lastSyncTime == 0 or lastSyncTime < time.time() - syncTimePeriod:
        log("Syncing time...")
        try:
            ntptime.settime()
        except Exception as e:
            log(repr(e))
            raise RainradarException("ERR NTP")
        log("Synced time with NTP server")
        lastSyncTime = time.time()

def getCurrentTime():
    return formatEmbTime(time.time()) + " UTC"

def formatEmbTime(embTime):
    return '{:04d}-{:02d}-{:02d} {:02d}:{:02d}:{:02d}'.format(*time.gmtime(embTime))

def setBrightness(disp, brightness, brightnessNight, timeNight):
    if brightnessNight != None and timeNight != None:
        curTime = str(time.gmtime()[3]) + ':' + str(time.gmtime()[4])
        if TimeFrame(timeNight).isInFrame(curTime):
            log("set night time brightness: " + str(brightnessNight))
            disp.setBrightness(brightnessNight)
            return
    if brightness == None:
        brightness = 10
    log("set daytime brightness: " + brightness)
    disp.setBrightness(brightness)
    
def updateRainRadarLevels():
    levelList = radar.getLevelList()
    log("rain radar records:")
    logLevels(levelList)
    disp.showRainLevels(levelList)
    setNextRadarSyncTime()
    
def logLevels(levelList):
    log(",".join(levelList))

def getRandomInt(base):
    return int(urandom.random() * base)
    
def setNextRadarSyncTime():
    global nextRadarSyncTime
    nextRadarSyncTime = time.time() + ( 2 * 60 ) + getRandomInt(10)
 
def showPause():
    log("Pause for " + str(nextRadarSyncTime - time.time()) + " seconds.")
    while(nextRadarSyncTime > time.time()):
        minutesToWait = math.ceil( (nextRadarSyncTime - time.time()) / 60 )
        disp.showWaitTime(minutesToWait)
        checkConfigMode()
        time.sleep(1)
        disp.showWaitTime(0)
        checkConfigMode()
        time.sleep(1)

def checkConfigMode():
    global configChanger, configMode
    #log("Config mode: " + str(configMode))
    if configMode != 0:
        log("Starting config changer...")
        configChanger.startServer()
        log("Config changer finished.")
        configMode = 0
        raise RainradarException("CONF EXIT")
    
def garbageCollector():
    gc.collect()
    log("Free memory: " + str(gc.mem_free()))
    
# main loop
while True:
    disp = Display()
    lastSyncTime = 0
    nextRadarSyncTime = 0
    try:
        cfg = Config()
        configChanger = ConfigChanger(cfg, disp)
        try:
            cfg.readConfig()
        except RainradarException as exp:
            log("Exception in readConfig: " + str(exp))
            configMode = 1
        checkConfigMode()
        plz = cfg.getPlz()
        disp.showText(plz, 2)
        checkConfigMode()
        wifi.connect(cfg.getSsid(), cfg.getPassword())
        radar = Radar(plz)
        while True:
            syncTime()
            setBrightness(disp, cfg.getBrightness(), cfg.getBrightnessNight(), cfg.getTimeNight())
            checkConfigMode()
            updateRainRadarLevels()
            checkConfigMode()
            showPause()
            garbageCollector()

    except RainradarException as rexp:
        strExp = str(rexp)
        log("RainradarException: " + strExp)
        disp.showText(strExp, 3)
        garbageCollector()
    except Exception as exp:
        strExp = str(exp)
        log("Unknown Exception: " + strExp)
        sys.print_exception(exp)
        with open("error.log", "w") as errorlog:
            print(getCurrentTime(), file=errorlog)
            sys.print_exception(exp, errorlog)
        while True: # stick on showing unknown exception
            disp.showText(strExp, 3)
            garbageCollector()

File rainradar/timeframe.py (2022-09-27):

class TimeFrame:

    def __init__(self, timeFrame):
        hourMinuteBegin, hourMinuteEnd = timeFrame.split('-')
        self.timeBegin = TimeFrame.__convert_to_decimal(hourMinuteBegin.strip())
        self.timeEnd = TimeFrame.__convert_to_decimal(hourMinuteEnd.strip())


    @staticmethod
    def __convert_to_decimal(timeStr):
        hour, min = tuple(timeStr.split(':'))
        converted = float(hour) + (float(min)/60)
        #print(timeStr + "->" + str(converted))
        return converted


    def isInFrame(self, hourMinute):
        time = TimeFrame.__convert_to_decimal(hourMinute)
        if self.timeBegin < self.timeEnd:
            return time >= self.timeBegin and time <= self.timeEnd
        elif self.timeBegin > self.timeEnd:
            return ( time >= self.timeBegin and time <= 24 )\
                or ( time <= self.timeEnd )
        else:
            return time == self.timeBegin


if __name__ == "__main__":
    print("6:08 - 15:30")
    timeFrame = TimeFrame("6:08 - 15:30")
    print("5:35", timeFrame.isInFrame("5:35"))
    print("10:15", timeFrame.isInFrame("10:15"))
    print("18:05 - 04:20")
    timeFrame = TimeFrame("18:05 - 04:20")
    print("3:35", timeFrame.isInFrame("3:35"))
    print("10:15", timeFrame.isInFrame("10:15"))
    print("16:15", timeFrame.isInFrame("16:15"))
    print("19:10", timeFrame.isInFrame("19:10"))

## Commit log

2021-08-26 first working prototype
2021-09-09 switched to the esp32 module
2021-09-15 added photo of the current status
2021-09-25 reset sync times in case of exception
    [main.py]
2021-09-26 switched to another DWD.de type for the rain forecast
2021-09-26 improved documentation
    [case_drillings.scad]
2021-10-03 present "Retest" and "Exit" as buttons
2021-10-03 fixed wrong connection status
    [config_changer.py]
2021-10-17 fixed issues if wifi name or password contains special characters
    [config_changer.py]
2021-10-17 fixed issues of the empty conf paramters if the boot button clicked at the start
    [main.py]
2021-10-17 added remark that the switching into configuration mode can take some seconds
2021-11-07 created new assemby folder with new pictures and exploded view
    [exploded_view.scad, exploded_view.stl]
2021-11-07 added dimensioning for casing and lid
    [casing.dxf, exploded_view.scad, lid.dxf]
2021-11-08 added schematics
    [schematic.dxf]
2021-11-09 improved schematic
    [schematic.dxf]
2021-11-09 created new assembly documentation
    [case_drillings.scad]
2021-11-10 improved assembly schematics
    [casing.dxf, exploded_view.scad, lid.dxf]
2021-11-14 added some assembly remarks
2022-01-06 fixed error in the pause calculation and log the current time more read friendly
    [main.py]
2022-01-06 fixed the calculation of the next time to call rain forecast and improved the log
    [main.py]
2022-01-07 added info about the CP210x driver
2022-06-06 implemented the new aws based backend to replace the 'morgenwirdes.de' backend
2022-07-04 switched from aws' simpledb to s3
2022-07-06 switched the rainradar to the aws backend
2022-07-11 improved the error detection and collection
    [config.py, main.py]
2022-07-16 fixed the display issue if the radar endpoint delivers http error
    [display.py, radar.py]
2022-09-27 reduce the pause between the backend calls from 5 to 2 mins to display more current data
2022-10-03 switched to new dwd_utils version with offline coordinate conversion
2022-10-03 switched to the new dwd_utils version with the offline coordinate mapping
2022-10-03 do not execute mosmix data parsing if the current data are the latest available
